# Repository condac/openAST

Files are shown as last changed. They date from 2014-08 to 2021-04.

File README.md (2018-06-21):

NEW! Arduino code
=================

I strongly recomend switching to the arduino based code. All future changes will be made here. It is much more easy to work with now that I have managed to get the critical timings right to send a correct signal. 

To add support for attiny in Arduino follow this guide https://create.arduino.cc/projecthub/arjun/programming-attiny85-with-arduino-uno-afb829

Do note that if you try to program your attiny mounted in the transponder you need to desolder the resistor on the antenna loop or the device will not respond correctly ( giving wrong board id errors and not responding well at all etc...) And you still need to supply the chip with an own oscilator source because it do not like to use the 20mhz crystal in programming mode for some reason.

openAST
=======

open source Axx Simulated transponder

This is for an attiny25 running at 20MHz

set fuse to -U lfuse:w:0xff:m in avrdude

To use the java program to encode run:

    cd encoderProgram/java/dist
    java -jar rctcode.jar 3456789

    encode2: 0101001000010111011001000101010000000000
    encodeOut:  1110000111001011111111010010100100101000000100110001110100010011001111110000
        ldi  d1,  0xe1
        ldi  d2,  0xcb
        ldi  d3,  0xfd
        ldi  d4,  0x29
        ldi  d5,  0x28
        ldi  d6,  0x13
        ldi  d7,  0x1d
        ldi  d8,  0x13
        ldi  d9,  0x3f
And the last lines you can paste in the asm file when you build your program and you have it ready to go. 

To decode, input a binary string as argument (at least 12 char) 

    java -jar rctcode.jar 1110000111001011111111010010100100101000000100110001110100010011001111110000
      known decoded: 01010010000101110110010001010100000000
      known decoded int: 3456789

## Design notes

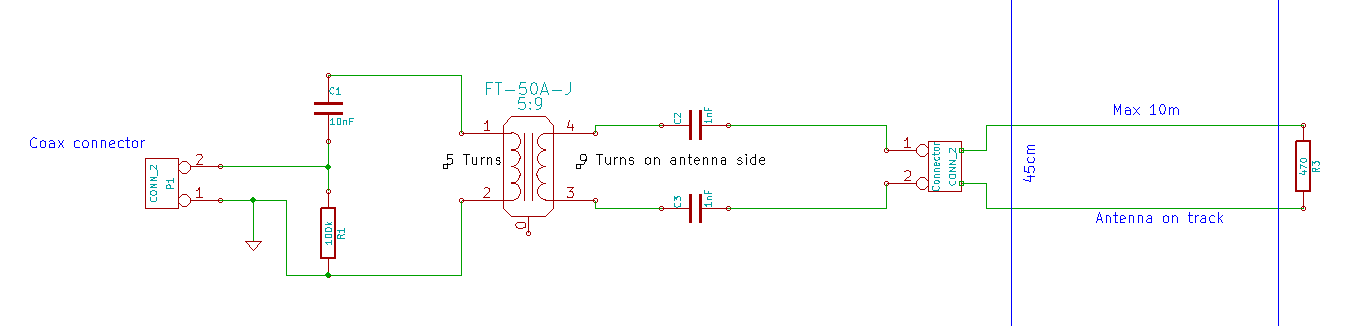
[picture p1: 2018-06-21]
circuitDesign/amb_blackbox/amb_blackbox_schema.png

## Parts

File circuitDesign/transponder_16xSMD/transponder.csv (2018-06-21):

Title
Revision
Date | 5 may 2015
Generated | Fri 25 May 2018 10:14:18 AM CEST
Company
Comment 1
Comment 2
Comment 3
Comment 4
Total Parts | 26
Total Unique Parts | 15
Ref | Qty | Value | Footprint | Datasheet
C1 C3 C5 C7 | 4 | 22pF | Capacitors_SMD:C_0805
C2 C6 | 2 | 1nF | Capacitors_SMD:C_0805
C4 C8 | 2 | 50uF | Capacitors_Tantalum_SMD:CP_Tantalum_Case-A_EIA-3216-18_Reflow
D1 D2 | 2 | LED | LEDs:LED_0805
D3 D4 | 2 | DIODE | Diodes_SMD:D_0805
IC1 | 1 | ATTINY85-P | Housings_DIP:DIP-8_W7.62mm_Socket
IC2 | 1 | ATTINY85-P | Housings_SOIC:SOIC-8_3.9x4.9mm_Pitch1.27mm
J1 | 1 | Conn_01x02 | Pin_Headers:Pin_Header_Straight_1x02_Pitch2.54mm
J2 | 1 | Conn_01x03 | Pin_Headers:Pin_Header_Straight_1x03_Pitch2.54mm
P1 P2 | 2 | CONN_2 | Connectors:PINHEAD1-2
R1 R3 | 2 | 220 | Resistors_SMD:R_0805
R2 R4 | 2 | 1k | Resistors_SMD:R_0805
U1 U2 | 2 | L78L05_SOT89 | TO_SOT_Packages_SMD:SOT-89-3
X1 | 1 | CRYSTAL | Crystals:Crystal_HC49-4H_Vertical
X2 | 1 | CRYSTAL | Crystals:Crystal_SMD_5032-2pin_5.0x3.2mm
BOM made with KICAD_BOM_WIZARD (https://github.com/HashDefineElectronics/KiCad_BOM_Wizard.git)
Generated Fri 25 May 2018 10:14:18 AM CEST

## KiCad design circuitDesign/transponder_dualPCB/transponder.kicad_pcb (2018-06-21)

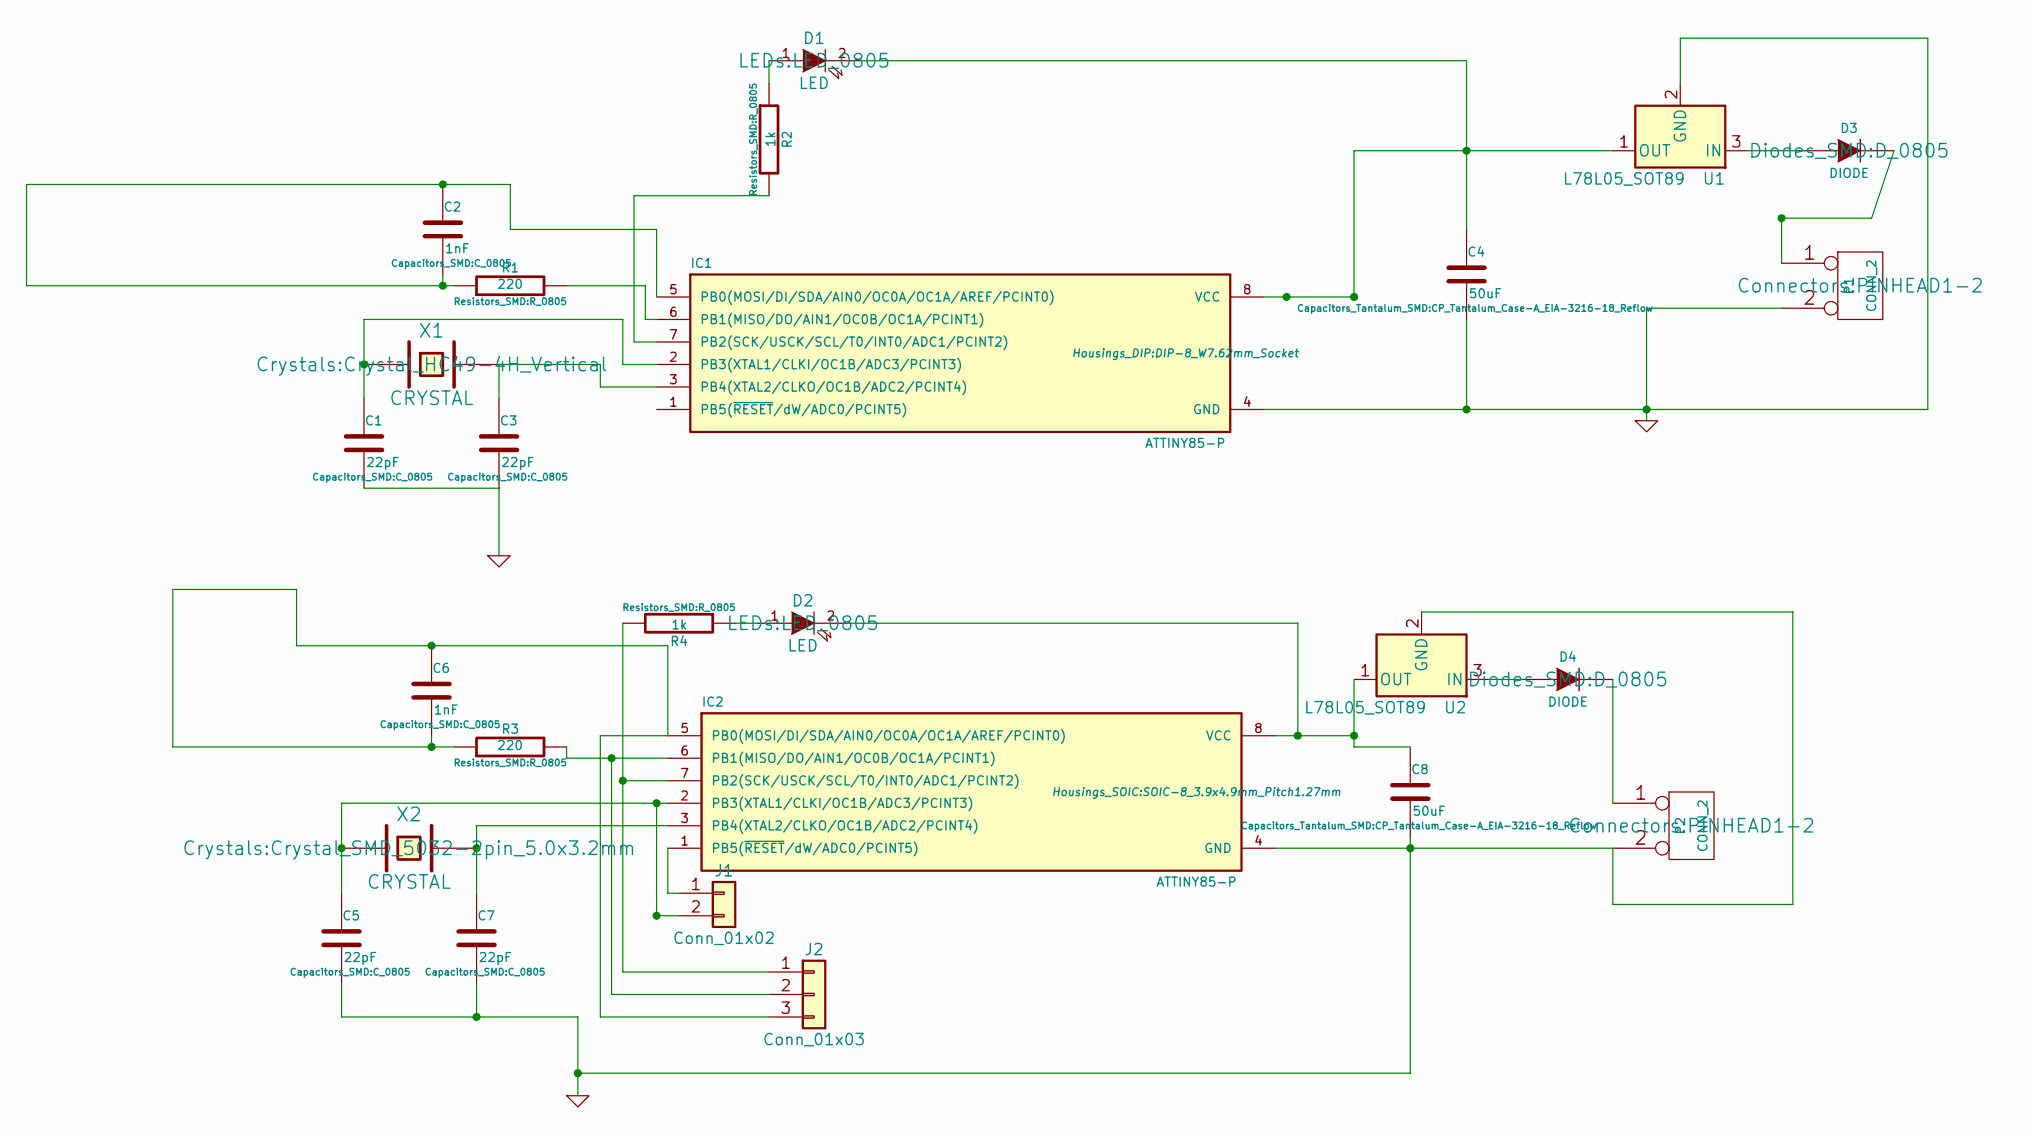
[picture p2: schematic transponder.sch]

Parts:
C1, C3, C5, C7: 22pF; C_0805
C2, C6: 1nF; C_0805
C4, C8: 50uF; CP_Tantalum_Case-A_EIA-3216-18_Reflow
D1, D2: LED; LED_0805
D3, D4: DIODE; D_0805
IC1: ATTINY85-P; DIP-8_W7.62mm_Socket
IC2: ATTINY85-P; SOIC-8_3.9x4.9mm_Pitch1.27mm
J1: Conn_01x02; Pin_Header_Straight_1x02_Pitch2.54mm
J2: Conn_01x03; Pin_Header_Straight_1x03_Pitch2.54mm
P1, P2: CONN_2; PINHEAD1-2
R1, R3: 220; R_0805
R2, R4: 1k; R_0805
U1, U2: L78L05_SOT89; SOT-89-3
X1: CRYSTAL; Crystal_HC49-4H_Vertical
X2: CRYSTAL; Crystal_SMD_5032-2pin_5.0x3.2mm

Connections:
GND: C1.2, C3.2, C4.2, C5.2, C7.2, C8.2, IC1.4 (GND), IC2.4 (GND), P1.2 (PM), P2.2 (PM), U1.2 (GND), U2.2 (GND)
unnamed: C1.1, IC1.2 (PB3(XTAL1/CLKI/OC1B/ADC3/PCINT3)), X1.1
unnamed: C2.1, C2.2, IC1.5 (PB0(MOSI/DI/SDA/AIN0/OC0A/OC1A/AREF/PCI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), R1.1
unnamed: C3.1, IC1.3 (PB4(XTAL2/CLKO/OC1B/ADC2/PCINT4)), X1.2
unnamed: C4.1, D1.2 (K), IC1.8 (VCC), U1.1 (OUT)
unnamed: C5.1, IC2.2 (PB3(XTAL1/CLKI/OC1B/ADC3/PCINT3)), J1.2, X2.1
unnamed: C6.1, C6.2, IC2.5 (PB0(MOSI/DI/SDA/AIN0/OC0A/OC1A/AREF/PCI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), J2.3, R3.1
unnamed: C7.1, IC2.3 (PB4(XTAL2/CLKO/OC1B/ADC2/PCINT4)), X2.2
unnamed: C8.1, D2.2 (K), IC2.8 (VCC), U2.1 (OUT)
unnamed: D1.1 (A), R2.1
unnamed: D2.1 (A), R4.1
unnamed: D3.1 (A), U1.3 (IN)
unnamed: D3.2 (K), P1.1
unnamed: D4.1 (A), U2.3 (IN)
unnamed: D4.2 (K), P2.1
unnamed: IC1.6 (PB1(MISO/DO/AIN1/OC0B/OC1A/PCINT1)), R1.2
unnamed: IC1.7 (PB2(SCK/USCK/SCL/T0/INT0/ADC1/PCINT2)), R2.2
unnamed: IC2.1 (PB5(~RESET~/dW/ADC0/PCINT5)), J1.1
unnamed: IC2.6 (PB1(MISO/DO/AIN1/OC0B/OC1A/PCINT1)), J2.2, R3.2
unnamed: IC2.7 (PB2(SCK/USCK/SCL/T0/INT0/ADC1/PCINT2)), J2.1, R4.2

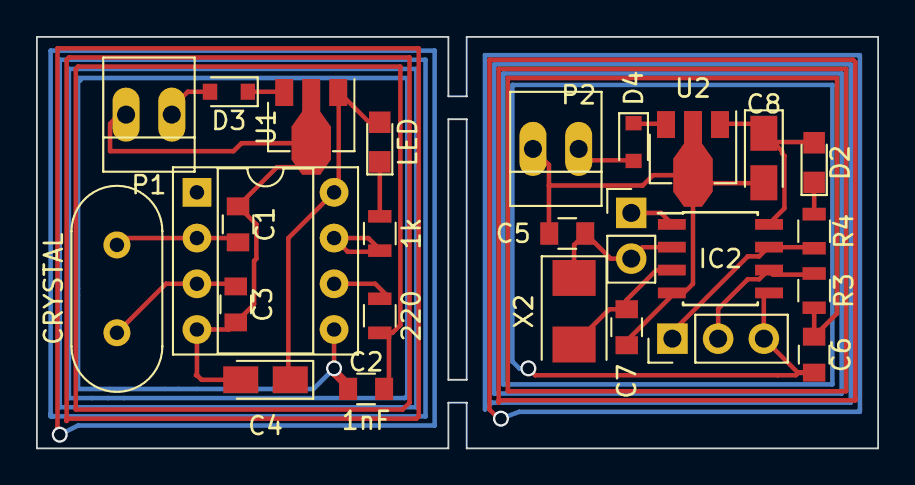
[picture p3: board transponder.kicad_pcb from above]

Board: 2 copper layers, 46.7 x 22.9 mm, 26 parts (0 on the bottom side), 20 nets.

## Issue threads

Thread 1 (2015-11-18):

schematic problem

aminear, 2015-11-18:
I think the diode at the input is backwards,  if the connector P1 is the power supply plug connector.
I built one from your schematic and it seems to work ok,  the led is blinking.  Now just need to test it on my decoder loop and see if it picks up.

condac, 2015-11-19:
The Diode D3 is supposed to be a reverse voltage protection, so you are right it is the wrong way.

aminear, 2015-11-19:
I don' the know how many times I have gotten them backwards.  I also left some coments on the transponder thread on rc tech.Com. but got it figured out about bse.exe vs rctcode.jar. thanks for you work.

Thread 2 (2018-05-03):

Modify arduinoISP to generate clock source for programming of attiny

condac, 2018-05-03:
Investigate if following code can generate a 4mhz clock and if it works to program a attiny with external clock bit set.

```
/*
    Prorotype Code for 1-4MHz PWM 50% Duty Cycle
    ICR1 as TOP = crystal / (2*Prescale*Fpwm)    in MODE 9

    at 16000000MHz   64 Prescale PWM Fmax = 62.5KHz
    at 16000000MHz    8 Prescale PWM Fmax = 500KHz
    at 16000000MHz    1 Prescale PWM Fmax = 4MHz

*/

void setup(){

  pinMode(9, OUTPUT);                              // OCR1A Output

  pinMode(10, OUTPUT);                             // Just test LED on OCR1B Generally LED
  digitalWrite(10, LOW);
  delay(1000);
  digitalWrite(10, HIGH);

//phase/frequency correct mode.

TCCR1A = _BV(COM1A1);                                               // Enable OCR1A
//TCCR1A = _BV(COM1A1) | _BV(COM1B1) ;                      // Enable OCR1A and OCAR1B
// TCCR1A = _BV(COM1A1) | _BV(COM1B1) | _BV(COM1A0) | _BV(COM1B0);

//TCCR1B = _BV(WGM13) | _BV(CS11);                                  // Set Prescale Clock 8 and Mode 9
TCCR1B = _BV(WGM13) | _BV(CS10);                                    // Set Prescale Clock 1 and Mode 9
}

void loop(){

//ICR minimum 2   F = 16000000MHz  No Change if using 14.7456MHz very close for fucking lazy bitch. and I don't need precision PWM at all.

16.MHz Xtal for PWM Frequency while 14.7456MHz for Precision Baudrate RS232/RS485/RS422

/*make this variable as table.
//ICR1 = 10,000;                     // 100Hz w/16MHz Prescale 8
//ICR1 = 5,000;                      // 200Hz w/16MHz Prescale 8

//TEST 500MHZ MAX
//ICR1 = 2;                            // 500KHz w/16MHz Prescale 8

// Test 4MHZ  MAX
ICR1 = 2;                                // 4MHz w/ 1600000MHz Prescale 1

OCR1A = ICR1 / 2;                    // 50 Duty of ICR1
}
```

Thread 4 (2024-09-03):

library files are missing or not found.

kiwidave72, 2024-09-03:
when opening up the schematic i get missing library files.
what library file/references  do i need  to download. i already  have a list of referenced libraries.

My library paths
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

Missing libraries
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

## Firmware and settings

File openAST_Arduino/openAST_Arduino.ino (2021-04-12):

/*
 * openAST Arduino rewrite
 * open source AMB Simulated transponder
 *  Created: 2014-07-21 16:09:20 Rewrite in arduino 2018
 *   Author: condac
 *
 *    Notes: This is the old AMB system not compatible with the new current RC4 system

 Copyright (C) 2014  condac

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
You should have received a copy of the GNU General Public License
along with this program; if not, write to the Free Software
Foundation, Inc., 51 Franklin Street, Fifth Floor, Boston, MA  02110-1301, USA.
 */


char timerstop = 0b01010000;
char timerstart = 0b01010001;

boolean sendStatus = false; // Set to true if you have status messages 1-7 that you know work

// 2351957
// ....................pre1  pre2  d1    d2    d3    d4    d5    d6    d7    d8    d9    d10
//char idMessage[12] = { 0XF9, 0X16, 0XE1, 0XCB, 0X12, 0X1C, 0XC9, 0XD6, 0XC3, 0XE0, 0XFF, 0X0F };
//char Status1[12]   = { 0xF9, 0x16, 0xDA, 0xE7, 0x94, 0x77, 0xE9, 0x3C, 0x91, 0xD7, 0xC3, 0xCC };
//char Status2[12]   = { 0xF9, 0x16, 0xEC, 0x50, 0x55, 0x92, 0xE2, 0x23, 0x61, 0xD4, 0xF0, 0x0C };
//char Status3[12]   = { 0xF9, 0x16, 0x36, 0x58, 0x15, 0x1B, 0xC8, 0xC3, 0x62, 0x14, 0x3C, 0x00 };
//char Status4[12]   = { 0xF9, 0x16, 0x0E, 0x29, 0xBA, 0xE0, 0x3E, 0xE3, 0x62, 0xDB, 0xC0, 0xC3 };
//char Status5[12]   = { 0xF9, 0x16, 0x36, 0x55, 0x57, 0x09, 0xFB, 0x3F, 0x91, 0x27, 0x00, 0xF0 };
//char Status6[12]   = { 0xF9, 0x16, 0x0E, 0xFE, 0xF0, 0x8A, 0x22, 0x3C, 0x52, 0x1B, 0x3F, 0xF3 };
//char Status7[12]   = { 0xF9, 0x16, 0xD7, 0xA8, 0x10, 0x77, 0xD1, 0x23, 0xA2, 0xD7, 0xC3, 0x3C };

//Status messages for custom numbers. Not sure if these work or just makes things worse. To use set sendStatus to true a few lines up
char idMessage[12] = { 0xF9, 0x16, 0x35, 0xDF, 0xDB, 0x12, 0xF1, 0x16, 0xC3, 0xEC, 0xF3, 0x30 }; // custom number
//char idMessage[12] = { 0xF9, 0x16, 0xFF, 0xFF, 0xFF, 0xFF, 0xFF, 0xFF, 0xFF, 0xFF, 0xFF, 0xFF}; // testmönster
char Status1[12]   = { 0xF9, 0x16, 0x03, 0xBC, 0x00, 0xC0, 0x3C, 0xFF, 0x40, 0x00, 0xC0, 0x3C };
char Status2[12]   = { 0xF9, 0x16, 0x00, 0x03, 0xBC, 0x00, 0xC0, 0x3F, 0x40, 0xFC, 0xC0, 0x3C };
char Status3[12]   = { 0xF9, 0x16, 0x03, 0xBF, 0xBC, 0xC0, 0xFC, 0xC3, 0xBC, 0xFC, 0xC0, 0x3C };
char Status4[12]   = { 0xF9, 0x16, 0x00, 0x00, 0x03, 0xBC, 0x00, 0xC3, 0x80, 0xFC, 0x3C, 0x3C };
char Status5[12]   = { 0xF9, 0x16, 0x03, 0xBC, 0x03, 0x7C, 0x3C, 0x3F, 0x7C, 0xFC, 0x3C, 0x3C };
char Status6[12]   = { 0xF9, 0x16, 0x00, 0x03, 0xBF, 0xBC, 0xC0, 0xFF, 0x7C, 0x00, 0x3C, 0x3C };
char Status7[12]   = { 0xF9, 0x16, 0x03, 0xBF, 0xBF, 0x7C, 0xFC, 0x03, 0x80, 0x00, 0x3C, 0x3C };

boolean ledStatus;
int ledCounter;

#define DELAY 1000
#define DELAY_RANDOM 1000

void setup() {
  pinMode(0,OUTPUT);
  pinMode(1,OUTPUT);
  pinMode(2,OUTPUT);

  TCCR1 = 0b01010001;  // set COM1A0 PWM1A CS10  COM1A0 tells the timer to Toggle the value on OC1A pins (page 89 attiny25 datasheet)
			//                       CS10 set timer prescale to 1
			 //            PWM1A enable pwm output
			// The timer needs to count to 255 before it starts to reset after 4 counts instead, don't know why
  OCR1A = 0x02;
  OCR1C = 0x03;


}

void messages() {
  sendData(idMessage);
  delayMicroseconds(DELAY+random(DELAY_RANDOM));
  sendData(idMessage);
  delayMicroseconds(DELAY+random(DELAY_RANDOM));
  sendData(idMessage);
  delayMicroseconds(DELAY+random(DELAY_RANDOM));
}

void loop() {

  digitalWrite(2,LOW);
  while (true) { // this while is not needed
    ledCounter++;
    if (ledCounter>50) {
      ledStatus = !ledStatus;
      ledCounter = 0;
    }
    messages();

    if (sendStatus) {

      sendData(Status1);
      delayMicroseconds(DELAY+random(DELAY_RANDOM));
      messages();

      sendData(Status2);
      delayMicroseconds(DELAY+random(DELAY_RANDOM));
      messages();

      sendData(Status3);
      delayMicroseconds(DELAY+random(DELAY_RANDOM));
      messages();

      sendData(Status4);
      delayMicroseconds(DELAY+random(DELAY_RANDOM));
      messages();

      sendData(Status5);
      delayMicroseconds(DELAY+random(DELAY_RANDOM));
      messages();

      sendData(Status6);
      delayMicroseconds(DELAY+random(DELAY_RANDOM));
      messages();

      sendData(Status7);
      delayMicroseconds(DELAY+random(DELAY_RANDOM));
    }
  }



  //delay(100);
}

void cycle_delay() {
  asm("nop");
  asm("nop");
  asm("nop");
  asm("nop");
  asm("nop");
}


void sendByte(char inData) {

// This do not work because the call to this function is to slow between each byte

  if( (inData & (1 << 7)) ) {
    TCCR1 = timerstop;
  }
  TCCR1 = timerstart; //
  cycle_delay();

  if( (inData & (1 << 6)) ) {
    TCCR1 = timerstop;
  }
  TCCR1 = timerstart; //
  cycle_delay();


  if( (inData & (1 << 5)) ) {
    TCCR1 = timerstop;
  }
  TCCR1 = timerstart; //
  cycle_delay();


  if( (inData & (1 << 4)) ) {
    TCCR1 = timerstop;
  }
  TCCR1 = timerstart; //
  cycle_delay();


  if( (inData & (1 << 3)) ) {
    TCCR1 = timerstop;
  }
  TCCR1 = timerstart; //
  cycle_delay();


  if( (inData & (1 << 2)) ) {
    TCCR1 = timerstop;
  }
  TCCR1 = timerstart;
  cycle_delay();


  if( (inData & (1 << 1)) ) {
    TCCR1 = timerstop;
  }
  TCCR1 = timerstart;
  cycle_delay();


  if( (inData & (1 << 0)) ) {
    TCCR1 = timerstop;
  }
  TCCR1 = timerstart;

  // TODO: look if the last delay is to long with the return calls

}
void sendData(char dataArray[]) {
  digitalWrite(2,HIGH); // stop led while sending data

  noInterrupts();
  OCR1A = 0x02;
  OCR1C = 0x03;
  // reset Timer/Counter prescaler
  GTCCR |= (1 << PSR1);
  // Zero (Reset) Timer1 8-bit up counter value
  TCNT1 = 0;
  TCCR1 = timerstart;
cycle_delay();
cycle_delay();
cycle_delay();
cycle_delay();


  sendByte(0x00);
  
 /* sendByte(dataArray[0]);
  sendByte(dataArray[1]);
  sendByte(dataArray[2]);
  sendByte(dataArray[3]);
  sendByte(dataArray[4]);
  sendByte(0xff);
  sendByte(dataArray[6]);
  sendByte(dataArray[7]);
  sendByte(dataArray[8]);
  sendByte(dataArray[9]);
  sendByte(dataArray[10]);
  sendByte(dataArray[11]);
*/
  int dataCounter = 0; //12*8;
  char bitCount = 7;
  int byteCount = 0;
  char inData = dataArray[dataCounter];
  
  while(dataCounter<=11) {
    if( (inData & (1 << 7)) ) {
      TCCR1 = timerstop;
    }
    asm("nop");
    TCCR1 = timerstart; //
    cycle_delay();
  
    if( (inData & (1 << 6)) ) {
      TCCR1 = timerstop;
    }
    asm("nop");
    TCCR1 = timerstart; //
    cycle_delay();
  
  
    if( (inData & (1 << 5)) ) {
      TCCR1 = timerstop;
    }
    asm("nop");
    TCCR1 = timerstart; //
    cycle_delay();
  
  
    if( (inData & (1 << 4)) ) {
      TCCR1 = timerstop;
    }
    asm("nop");
    TCCR1 = timerstart; //
    cycle_delay();
  
  
    if( (inData & (1 << 3)) ) {
      TCCR1 = timerstop;
    }
    asm("nop");
    TCCR1 = timerstart; //
    cycle_delay();
  
  
    if( (inData & (1 << 2)) ) {
      TCCR1 = timerstop;
    }
    asm("nop");
    TCCR1 = timerstart;
    cycle_delay();
  
  
    if( (inData & (1 << 1)) ) {
      TCCR1 = timerstop;
    }
    asm("nop");
    TCCR1 = timerstart;
    cycle_delay();
  
  
    if( (inData & (1 << 0)) ) {
      TCCR1 = timerstop;
    }
    asm("nop");
    TCCR1 = timerstart;
    dataCounter++;
    inData = dataArray[dataCounter];

    asm("nop");
    asm("nop");
    asm("nop");
    asm("nop");
    
    
  }
  cycle_delay();
  cycle_delay();

  TCCR1 = timerstop; //out  TCCR1,timerstop // Shut down radio
                     //ldi  slask, 0b0100_0000 // set COM1A0 (bit4) to 0 to disconnect timer pins
  TCCR1 = 0b01000000;//out  TCCR1,slask
  interrupts();



  digitalWrite(0,LOW);//cbi  PORTB, 0  // set both output to 0 to avoid current drain
  digitalWrite(1,LOW);//cbi  PORTB, 1  // set both output to 0 to avoid current drain
  digitalWrite(2,ledStatus);
}

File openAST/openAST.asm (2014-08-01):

/*
 * openAST.asm
 * open source AMB Simulated transponder
 *  Created: 2014-07-21 16:09:20
 *   Author: condac
 *
 *    Notes: This is the old AMB system not compatible with the new current RC4 system

 Copyright (C) 2014  condac

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
You should have received a copy of the GNU General Public License
along with this program; if not, write to the Free Software
Foundation, Inc., 51 Franklin Street, Fifth Floor, Boston, MA  02110-1301, USA.
 */ 


 .include "tn25def.inc" 
 .def slask=r16 // slask = temp
 .def timerstop=r17
 .def timerstart=r18
 .def pre1=r19
 .def pre2=r20
 .def d1=r21
 .def d2=r22
 .def d3=r23
 .def d4=r24
 .def d5=r25
 .def d6=r26
 .def d7=r27
 .def d8=r28
 .def d9=r29
 .def d10=r30
 .def d11=r31


reset:
	rjmp start
start:
	//Setup timer to flip OC1A and OC1A inverted
	// To take advantage of the inverted pin of the timer output we must be in PWM mode

	ldi  timerstop, 0b0101_0000
	ldi  timerstart, 0b0101_0001 // set COM1A0 PWM1A CS10  COM1A0 tells the timer to Toggle the value on OC1A pins (page 89 attiny25 datasheet)
	out  TCCR1,timerstart        //                       CS10 set timer prescale to 1
							     //						 PWM1A enable pwm output
								 // The timer needs to count to 255 before it starts to reset after 4 counts instead, don't know why

	ldi  slask, 0x02 // set the counter trigger value, the value the timer will count to before toggle the timer pin
	out  OCR1A,slask
	ldi  slask, 0x03 // set the counter trigger value, the value the timer will count to before toggle the timer pin
	out  OCR1C,slask

	in slask,TIFR 
	sbr slask,TOV1
	out TIFR,slask 

	ldi  slask, 0x07
	out	 DDRB, slask   // PORTB => output

	// Set transponder code

	ldi  pre1, 0xF9  // Header bit 1-8  // Never change
	ldi  pre2, 0x16  // Header bit 9-16 // Never change
		
	ldi  d1,  0xE1
	ldi  d2,  0xCB
	ldi  d3,  0xFD
	ldi  d4,  0x29
	ldi  d5,  0x28
	ldi  d6,  0x13
	ldi  d7,  0x1d
	ldi  d8,  0x13
	ldi  d9,  0x3f
	ldi  d10, 0x00
	ldi  d11, 0x00 // End
	


	sts  0x0159, d11

	rjmp loop
	


loop:
	///////////////////////////////////////////////////MAIN LOOOP ///////////////////////////////////////////////////////
	// start radio
	out  TCCR1,timerstart // Start radio

	nop

	// wait a bit for radio to start
	ldi  slask, 0b0011_0000
	rcall pre_delay

	// send data
	rcall pre_delay
	rcall send_data
	//rcall pre_delay
	//rcall send_data
	//rcall pre_delay
	//rcall send_data
	// small delay and then send again
	//rcall pre_delay
	//rcall send_data

    // small delay and then send again
	//rcall pre_delay
	//rcall send_data

	
	out  TCCR1,timerstop // Shut down radio
	ldi  slask, 0b0100_0000 // set COM1A0 (bit4) to 0 to disconnect timer pins
	out  TCCR1,slask
	cbi  PORTB, 0  // set both output to 0 to avoid current drain
	cbi  PORTB, 1  // set both output to 0 to avoid current drain

	
	lds  slask, 0x0160 // load led counter from ram
	lds  d11, 0x0161
	cbi  PORTB, 2
	inc  slask
	BREQ ledtimer
ledreturn:
    SBRC d11,0 ; Skip the next instruction if bit is 0
	sbi  PORTB, 2  // set led
	nop
	sts  0x0160, slask
	sts  0x0161, d11
	lds  d11, 0x0159
	clv 

	// time between each send 3ms
	rcall delay_loop
	rcall delay_loop
	rcall delay_loop

    rcall delay_loop
	rcall delay_loop
	rcall delay_loop
	rcall delay_loop
	/*
    rcall delay_loop	
	rcall delay_loop
	rcall delay_loop
	rcall delay_loop

    rcall delay_loop
	rcall delay_loop
	rcall delay_loop
	rcall delay_loop
	
    rcall delay_loop
	*/
	rjmp loop
	///////////////////////////////////////////////////END  MAIN LOOOP ///////////////////////////////////////////////////////

test:
		// interupt timer
	ldi  slask, 0b0101_0000 // stop timer
	out  TCCR1,slask
	ldi  slask, 0b0101_0001 // start timer
	out  TCCR1,slask

delay_loop:  // Time between each signal burst
   nop
   dec   slask       
   brne   delay_loop 
   ret

pre_delay: // Time to spool up radio signal
   dec   slask       
   brne   pre_delay 
   ret

cycle_delay:
	// When this is empty the cycle time makes it 11 cycles between each number
	// to get 16 cycles we add 5 extra nop
	nop
	nop
	nop
	nop
	nop

	ret
ledtimer: 
	inc d11
	rjmp ledreturn

send_data:
   	// Start header signal

	SBRC pre1,7 ; Skip the next instruction if bit is 0
    out  TCCR1,timerstop// if 1
    nop
	out  TCCR1,timerstart// if 0 and after if 1
	rcall cycle_delay

	SBRC pre1,6 ; Skip the next instruction if bit is 0
    out  TCCR1,timerstop// if 1
	nop
	out  TCCR1,timerstart// if 0 and after if 1
	rcall cycle_delay

	SBRC pre1,5 ; Skip the next instruction if bit is 0
    out  TCCR1,timerstop// if 1
	nop
	out  TCCR1,timerstart// if 0 and after if 1
	rcall cycle_delay

	SBRC pre1,4 ; Skip the next instruction if bit is 0
    out  TCCR1,timerstop// if 1
	nop
	out  TCCR1,timerstart// if 0 and after if 1
	rcall cycle_delay

	SBRC pre1,3 ; Skip the next instruction if bit is 0
    out  TCCR1,timerstop// if 1
	nop
	out  TCCR1,timerstart// if 0 and after if 1
	rcall cycle_delay

	SBRC pre1,2 ; Skip the next instruction if bit is 0
    out  TCCR1,timerstop// if 1
	nop
	out  TCCR1,timerstart// if 0 and after if 1
	rcall cycle_delay

	SBRC pre1,1 ; Skip the next instruction if bit is 0
    out  TCCR1,timerstop// if 1
	nop
	out  TCCR1,timerstart// if 0 and after if 1
	rcall cycle_delay

	SBRC pre1,0 ; Skip the next instruction if bit is 0
    out  TCCR1,timerstop// if 1
	nop
	out  TCCR1,timerstart// if 0 and after if 1
	rcall cycle_delay
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

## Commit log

2014-08-01 Added KiCAD schematics for hardware
    [circuitDesign.sch]
2014-08-01 Added diode values
    [circuitDesign.sch]
2015-08-18 update circuit
    [amb_blackbox.sch, circuitDesign.sch, transponder.kicad_pcb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]
2018-05-02 Added Arduino version of code
2018-05-04 Working encoderprogram for python
2018-05-10 First working arduino version
2018-05-14 Updated blackbox with working and tested design
    [amb_blackbox.sch]
2018-05-24 PCB work, and more
    [transponder.kicad_pcb, transponder.sch]
2018-05-24 PCB print version
    [transponder.kicad_pcb]
2018-05-25 fixed pcb text on soldermasks
    [transponder-B.Cu.gbl, transponder-B.Mask.gbs, transponder-B.SilkS.gbo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]
2018-05-25 4x4 array for pcb printing
    [transponder.csv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]
2021-04-12 Fix so transponder is using same phase every time
    [openAST_Arduino.ino]

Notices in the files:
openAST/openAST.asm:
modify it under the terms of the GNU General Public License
